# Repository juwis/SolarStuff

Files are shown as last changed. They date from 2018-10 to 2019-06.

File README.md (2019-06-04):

# SolarStuff on SolarFlight.info
1. brushless esc with integrated MPPT
 * [Software](https://github.com/juwis/SolarStuff/tree/master/src/autompptbldc)
 * [Hardware](https://github.com/juwis/SolarStuff/tree/master/hardware)
2. Solar Flight optimized Propellers
 * [CAD Data, Prop Data](https://github.com/juwis/SolarStuff/tree/master/props)
3. ...

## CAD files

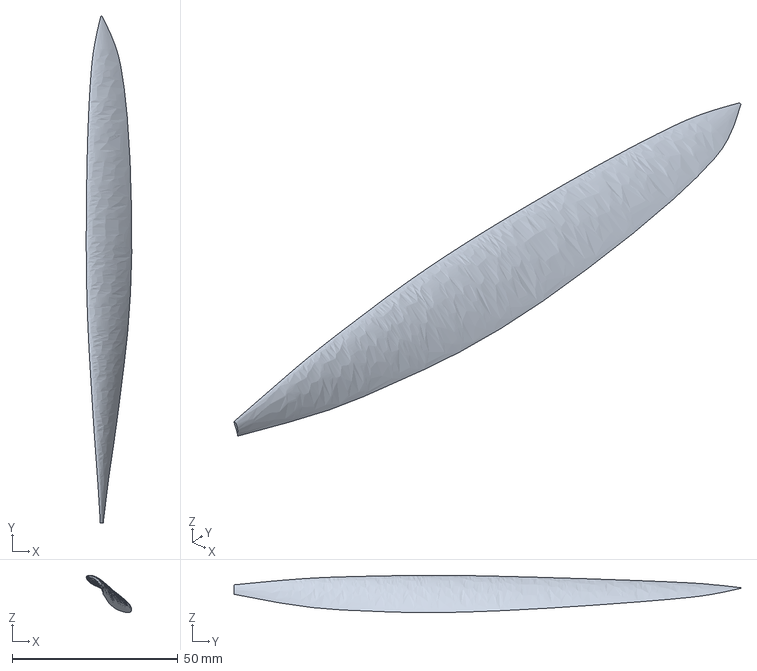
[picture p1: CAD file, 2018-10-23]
props/PROP_NG/13x18_schmal.igs
13.7 x 153.0 x 11.3 mm

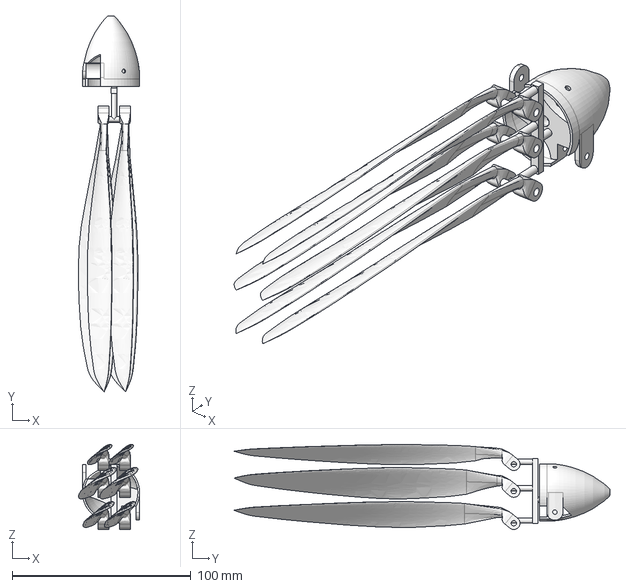
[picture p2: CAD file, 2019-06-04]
props/triple_size_spinner_4mm.stp
34.3 x 210.3 x 47.5 mm

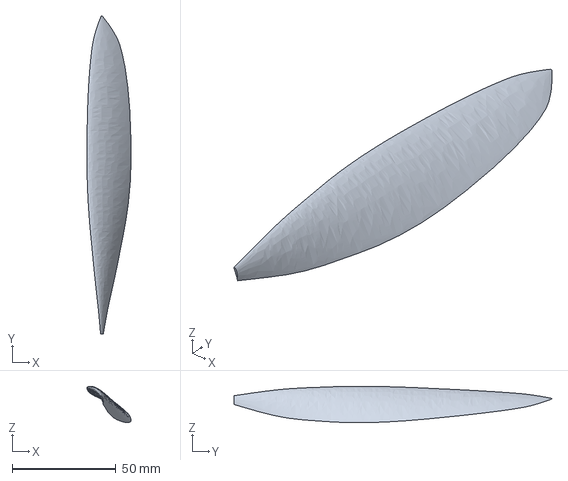
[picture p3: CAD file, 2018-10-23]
props/PROP_NG/13x18_breit.igs
21.2 x 153.0 x 17.5 mm

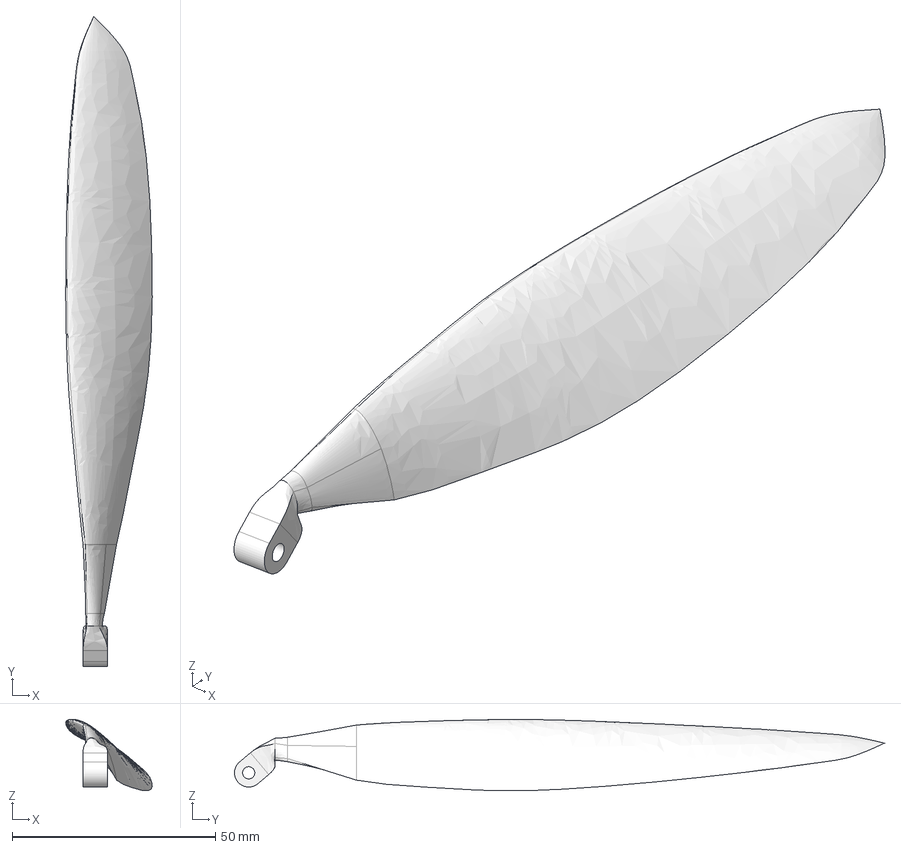
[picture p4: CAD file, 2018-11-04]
props/13x18_breit_blatthalter.stp
21.3 x 160.0 x 17.6 mm

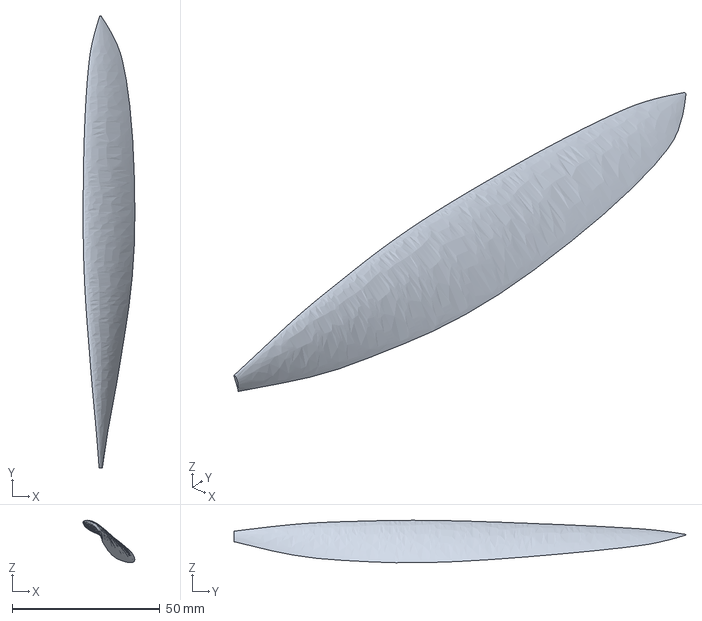
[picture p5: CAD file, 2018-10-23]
props/PROP_NG/13x18_mittel.igs
17.5 x 153.0 x 14.4 mm

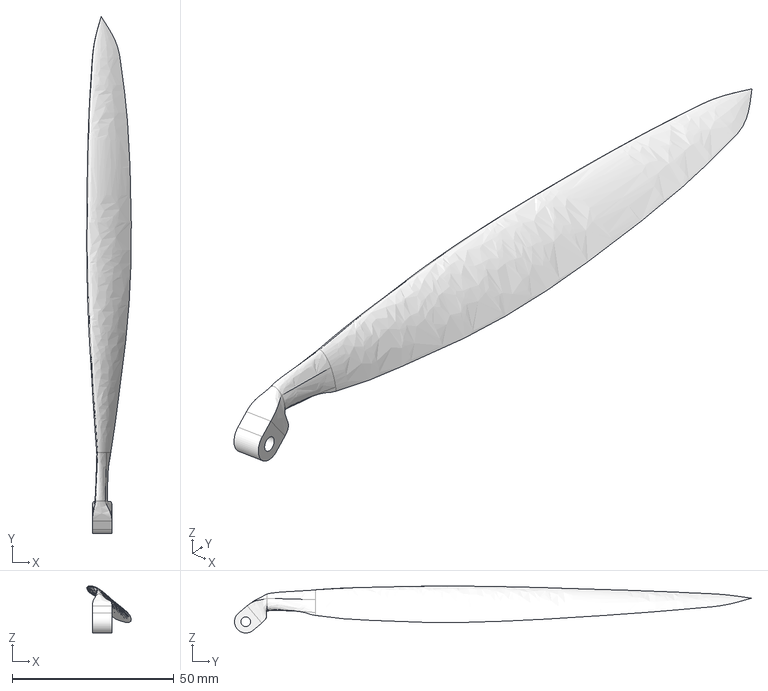
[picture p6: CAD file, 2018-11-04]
props/13x18_schmal_blatthalter.stp
13.8 x 160.0 x 14.5 mm

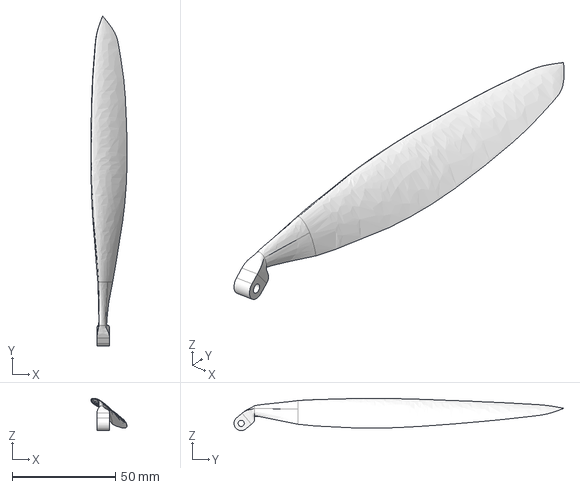
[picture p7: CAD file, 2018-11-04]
props/13x18_mittell_blatthalter.stp
17.6 x 160.0 x 15.6 mm

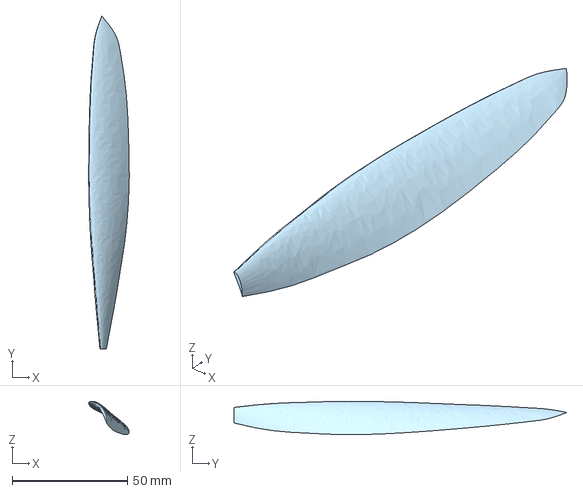
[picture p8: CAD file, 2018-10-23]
props/13x18_mittel_solid.step
17.6 x 144.5 x 14.4 mm

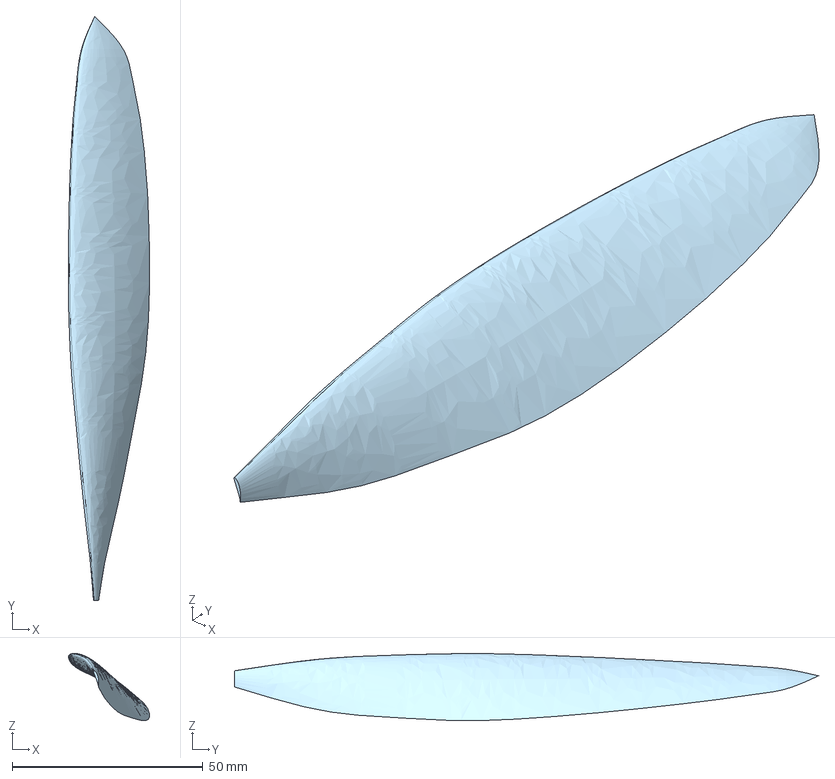
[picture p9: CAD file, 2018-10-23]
props/13x18_breit_solid.step
21.3 x 153.0 x 17.6 mm

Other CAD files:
props/triple_size_spinner_3.17mm.stp
props/13x18_schmal_solid.step

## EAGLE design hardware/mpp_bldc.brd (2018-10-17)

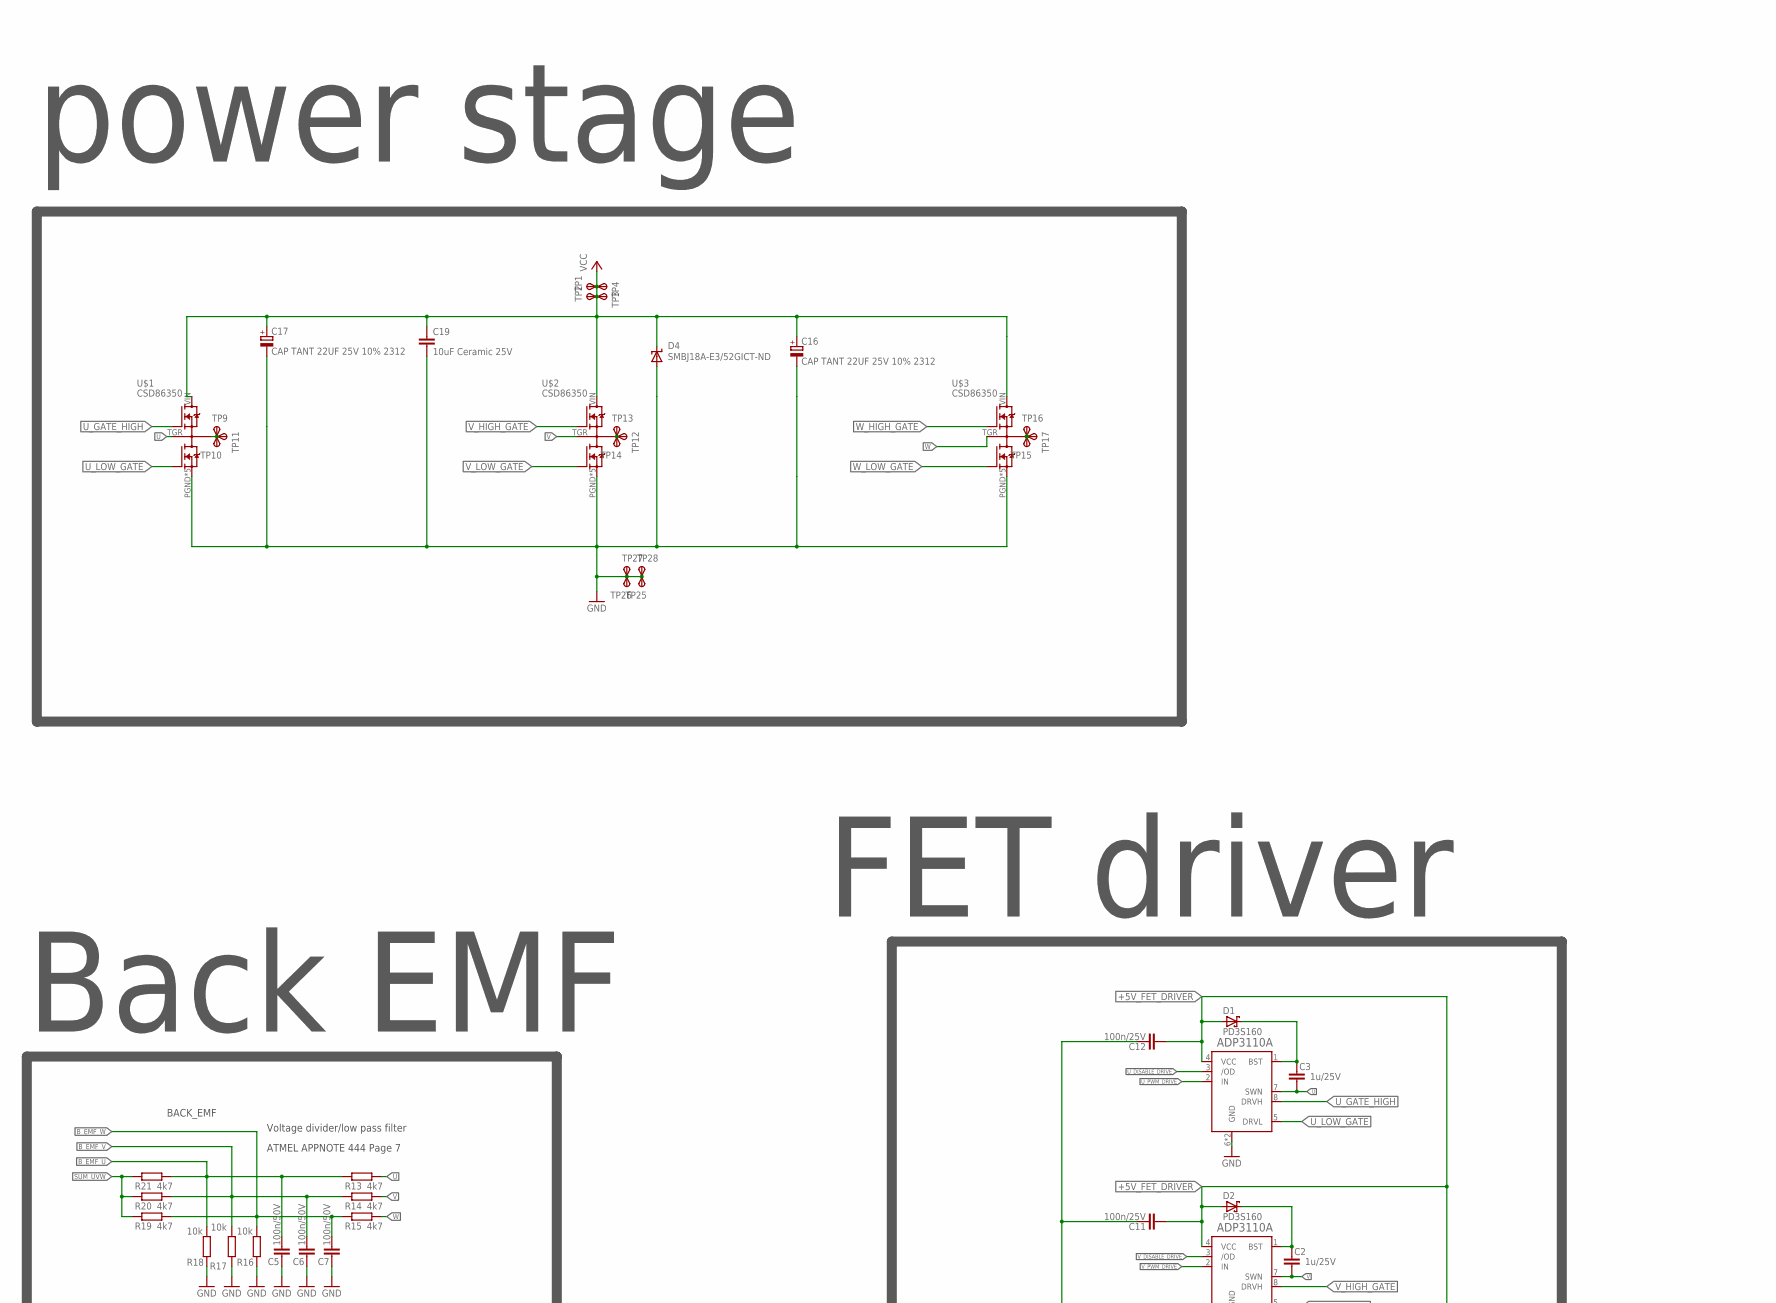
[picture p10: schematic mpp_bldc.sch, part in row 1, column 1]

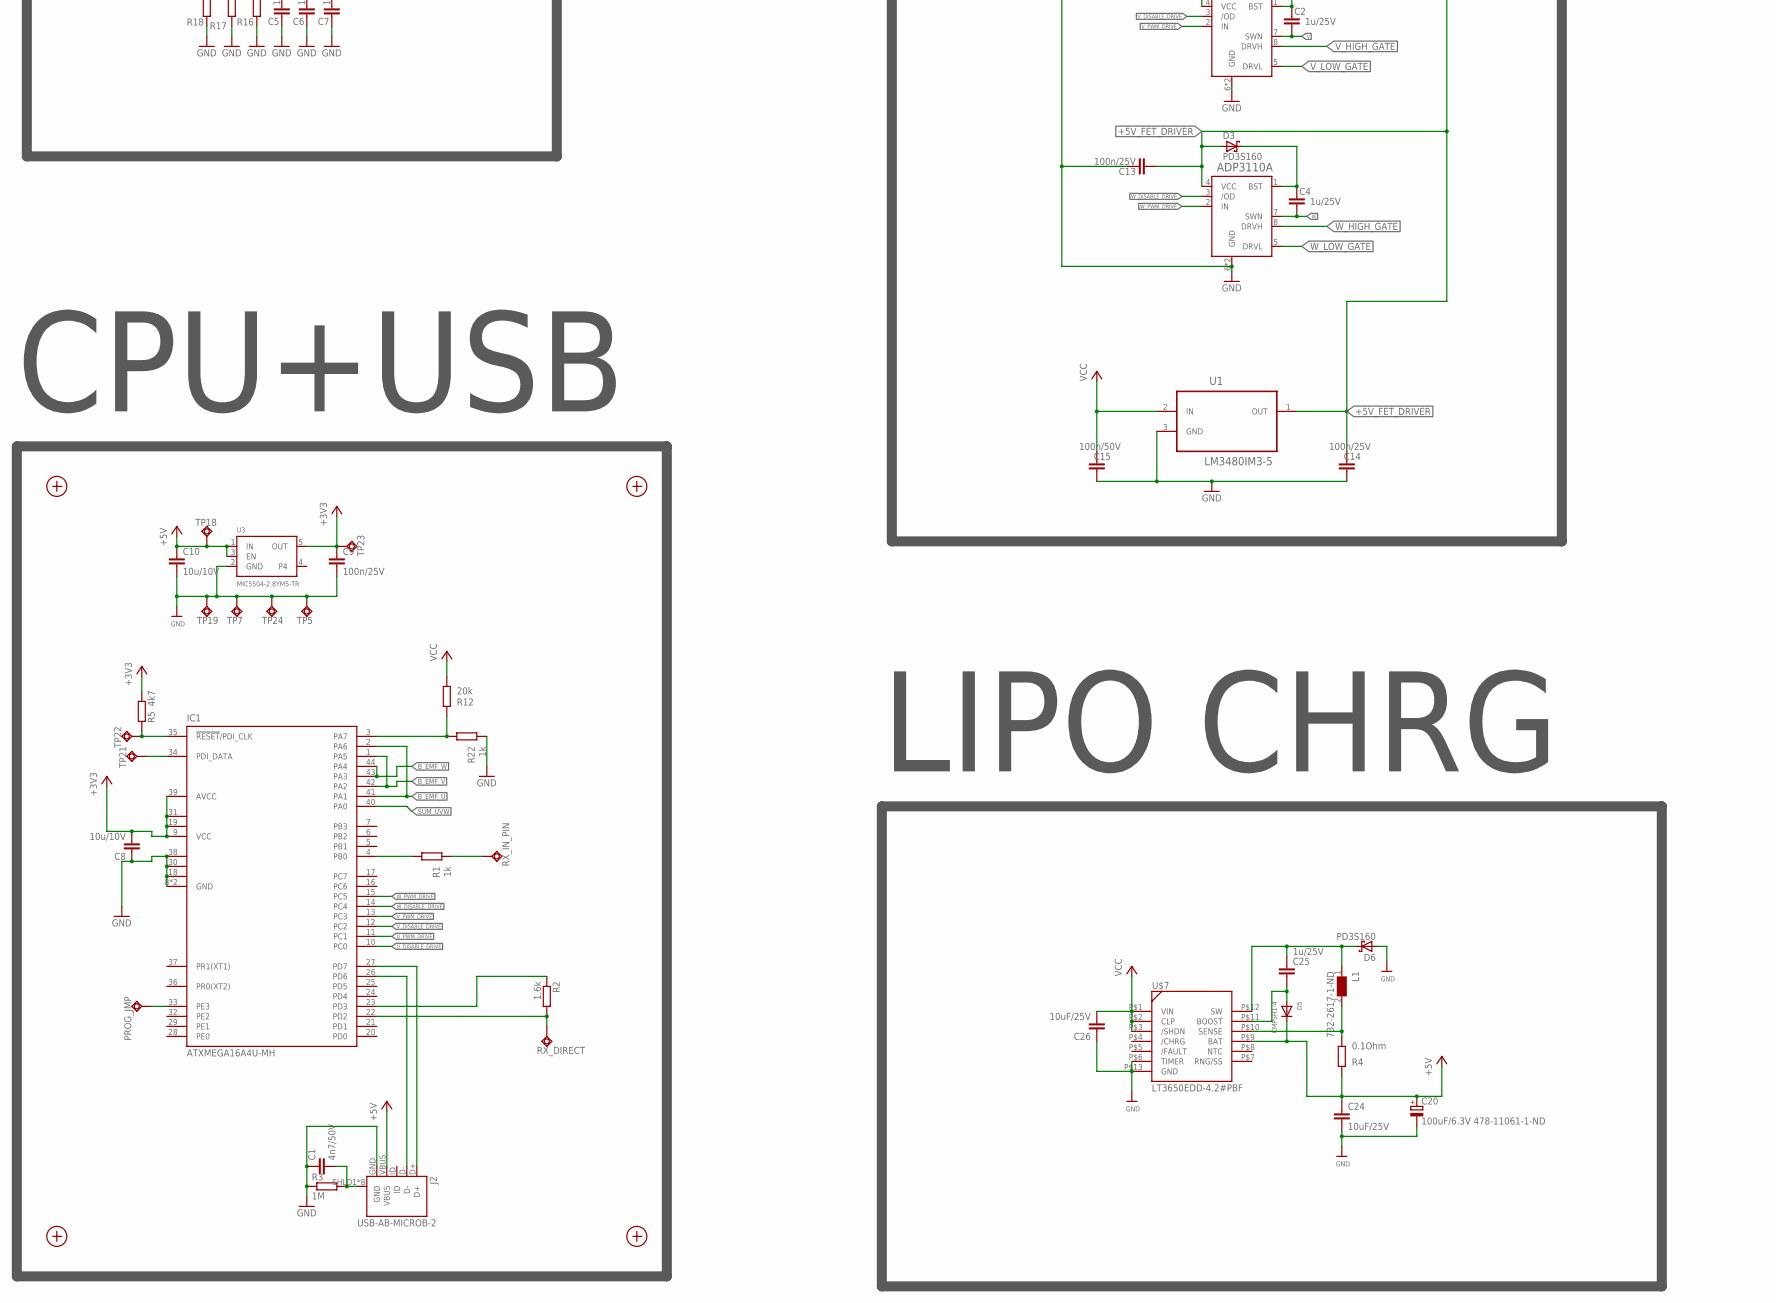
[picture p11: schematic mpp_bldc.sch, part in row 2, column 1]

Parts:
C1: 4n7/50V; C0603
C2, C3, C4, C25: 1u/25V; C0603
C5, C6, C7, C15: 100n/50V; C0603
C8, C10: 10u/10V; C0603K
C9, C11, C12, C13, C14: 100n/25V; C0603
C16, C17: CAP TANT 22UF 25V 10% 2312; C/6032-28R
C19: 10uF Ceramic 25V; C1206
C20: 100uF/6.3V 478-11061-1-ND; CT7343
C24, C26: 10uF/25V; C0805
D1, D2, D3, D6: PD3S160; POWERDI323
D4: SMBJ18A-E3/52GICT-ND; SMBJ
D5: CMPSH1-4; SOT23-R
IC1: ATXMEGA16A4U-MH; MLF44-TH
J2: USB-AB-MICROB-2; USB-MICROB-10118194
L1: 732-2617-1-ND; WE-TPC_2828
PROG_JMP: TPSQTP19SQ; TP19SQ
R1, R22: 1k; R0603
R2: 1.6k; R0603
R3: 1M; R0603
R4: 0.1Ohm; R0402
R5, R13, R14, R15, R19, R20, R21: 4k7; R0603
R12: 20k; R0603
R16, R17, R18: 10k; R0603
RX_DIRECT: TPSQTP19SQ; TP19SQ
RX_IN_PIN: TPSQTP19SQ; TP19SQ
TP1, TP2, TP3, TP4, TP9, TP10, TP11, TP12, TP13, TP14, TP15, TP16, TP17, TP25, TP26, TP27, TP28: TPSTP20SQ; TP20SQ
TP5, TP7, TP18, TP19: TPSQTP19SQ; TP19SQ
TP21: TPSQTP15R; TP15R
TP22, TP23, TP24: TPSQTP14SQ; TP14SQ
U1: LM3480IM3-5; SOT95P251X112-3N
U3: MIC5504-2.8YM5-TR; SOT23-5
U$1, U$2, U$3: CSD86350; Q5D
U$4, U$5, U$6: ADP3110A; DFN-8
U$7: LT3650EDD-4.2#PBF; 12-WFDFN
X1, X2, X3, X4: PASSER-07; PASSER_07MM

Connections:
+3V3: C8.2, C9.1, IC1.9 (VCC), IC1.19 (VCC1), IC1.31 (VCC2), IC1.39 (AVCC), R5.1, TP23.TP, U3.5 (OUT)
+5V: C10.1, C20.+, C24.1, D5.3 (C), J2.VBUS, R4.2, TP18.TP, U3.1 (IN), U3.3 (EN), U$7.P$9 (BAT)
+5V_FET_DRIVER: C11.2, C12.2, C13.2, C14.2, D1.A, D2.A, D3.A, U1.1 (OUT), U$4.4 (VCC), U$5.4 (VCC), U$6.4 (VCC)
B_EMF_U: C5.1, IC1.2 (PA6), IC1.41 (PA1), R13.2, R18.1, R21.1
B_EMF_V: C6.1, IC1.1 (PA5), IC1.42 (PA2), R14.2, R17.1, R20.1
B_EMF_W: C7.1, IC1.43 (PA3), IC1.44 (PA4), R15.2, R16.1, R19.1
GND: C1.1, C5.2, C6.2, C7.2, C8.1, C9.2, C10.2, C11.1, C12.1, C13.1, C14.1, C15.1, C16.-, C17.-, C19.2, C20.-, C24.2, C26.1, D4.A, D6.A, IC1.8 (GND), IC1.18 (GND1), IC1.30 (GND2), IC1.38 (GND3), IC1.TH (GND), J2.GND, R3.1, R16.2, R17.2, R18.2, R22.1, TP5.TP, TP7.TP, TP19.TP, TP24.TP, TP25.TP, TP26.TP, TP27.TP, TP28.TP, U1.3 (GND), U3.2 (GND), U$1.PGND, U$1.PGND0 (PGND), U$1.PGND1 (PGND), U$1.PGND2 (PGND), U$1.PGND3 (PGND), U$2.PGND, U$2.PGND0 (PGND), U$2.PGND1 (PGND), U$2.PGND2 (PGND), U$2.PGND3 (PGND), U$3.PGND, U$3.PGND0 (PGND), U$3.PGND1 (PGND), U$3.PGND2 (PGND), U$3.PGND3 (PGND), U$4.6 (GND), U$4.PAD (GND), U$5.6 (GND), U$5.PAD (GND), U$6.6 (GND), U$6.PAD (GND), U$7.P$6 (TIMER), U$7.P$13 (GND)
unnamed: IC1.33 (PE3), PROG_JMP.TP
unnamed: IC1.3 (PA7), R12.2, R22.2
unnamed: C3.2, D1.C, U$4.1 (BST)
unnamed: IC1.27 (PD7), J2.D+
unnamed: IC1.26 (PD6), J2.D-
unnamed: C2.2, D2.C, U$5.1 (BST)
unnamed: C4.2, D3.C, U$6.1 (BST)
unnamed: C25.1, D6.C, L1.1, U$7.P$12 (SW)
unnamed: L1.2, R4.1, U$7.P$10 (SENSE)
unnamed: C1.2, J2.SHLD1 (SHIELD), J2.SHLD2 (SHIELD), J2.SHLD3 (SHIELD), J2.SHLD4 (SHIELD), J2.SHLD5 (SHIELD), J2.SHLD6 (SHIELD), J2.SHLD7 (SHIELD), J2.SHLD8 (SHIELD), R3.2
unnamed: C25.2, D5.1 (A), U$7.P$11 (BOOST)
PDI_DATA: IC1.34 (PDI_DATA), TP21.TP
RC_SIG_IC: IC1.4 (PB0), R1.2
RC_SIG_RCV: R1.1, RX_IN_PIN.TP
RST_PDICLK: IC1.35 (!RESET!/PDI_CLK), R5.2, TP22.TP
RX_DIRECT_PD2: IC1.22 (PD2), R2.2, RX_DIRECT.TP
SUM_UVW: IC1.40 (PA0), R19.2, R20.2, R21.2
TX_DIRECT_PD3: IC1.23 (PD3), R2.1
U: C3.1, R13.1, U$1.TGR, U$4.7 (SWN)
UMOT: TP9.TP, TP10.TP, TP11.TP, U$1.VSW0 (VSW), U$1.VSW1 (VSW), U$1.VSW2 (VSW)
U_DISABLE_DRIVE: IC1.10 (PC0), U$4.3 (/OD)
U_GATE_HIGH: U$1.TG, U$4.8 (DRVH)
U_LOW_GATE: U$1.BG, U$4.5 (DRVL)
U_PWM_DRIVE: IC1.11 (PC1), U$4.2 (IN)
V: C2.1, R14.1, U$2.TGR, U$5.7 (SWN)
VCC: C15.2, C16.+, C17.+, C19.1, C26.2, D4.C, R12.1, TP1.TP, TP2.TP, TP3.TP, TP4.TP, U1.2 (IN), U$1.VIN, U$2.VIN, U$3.VIN, U$7.P$1 (VIN), U$7.P$2 (CLP), U$7.P$3 (/SHDN)
VMOT: TP12.TP, TP13.TP, TP14.TP, U$2.VSW0 (VSW), U$2.VSW1 (VSW), U$2.VSW2 (VSW)
V_DISABLE_DRIVE: IC1.12 (PC2), U$5.3 (/OD)
V_HIGH_GATE: U$2.TG, U$5.8 (DRVH)
V_LOW_GATE: U$2.BG, U$5.5 (DRVL)
V_PWM_DRIVE: IC1.13 (PC3), U$5.2 (IN)
W: C4.1, R15.1, U$3.TGR, U$6.7 (SWN)
WMOT: TP15.TP, TP16.TP, TP17.TP, U$3.VSW0 (VSW), U$3.VSW1 (VSW), U$3.VSW2 (VSW)
W_DISABLE_DRIVE: IC1.14 (PC4), U$6.3 (/OD)
W_HIGH_GATE: U$3.TG, U$6.8 (DRVH)
W_LOW_GATE: U$3.BG, U$6.5 (DRVL)
W_PWM_DRIVE: IC1.15 (PC5), U$6.2 (IN)

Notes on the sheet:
Voltage divider/low pass filter
ATMEL APPNOTE 444 Page 7
BACK_EMF
power stage
FET driver
LIPO CHRG
Back EMF
CPU+USB

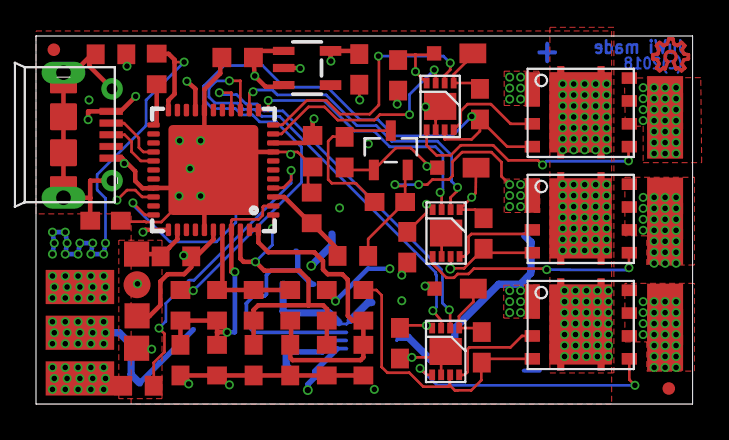
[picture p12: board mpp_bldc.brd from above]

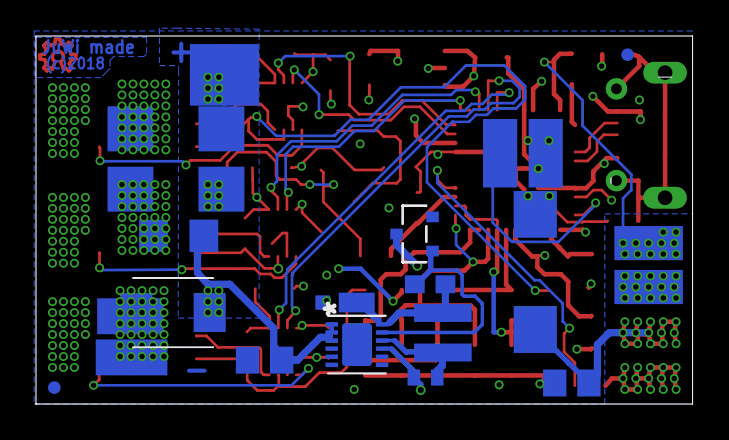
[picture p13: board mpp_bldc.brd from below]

Board: 4 copper layers, 36.5 x 20.4 mm, 89 parts (27 on the bottom side), 44 nets.

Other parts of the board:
U$11: OSHW_2MM

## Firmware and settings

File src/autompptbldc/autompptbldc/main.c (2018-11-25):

/*
* autompptbldc.c
*
* Created: 8/3/2018 12:49:07 PM
* Author : juwi
*/

#include "includes.h"
#include "constants.h"
#include "setup.h"
#include "uart.h"

//#define DEBUG_SERIAL


volatile unsigned char COMMUTATION_INDEX_SENSED, COMMUTATION_INDEX;
volatile uint32_t RT_TIME[6];
volatile uint16_t ADC;
volatile unsigned int BREAK;
volatile uint16_t average_time;

volatile float COMMUTATION_TIMING_FACTOR;

volatile uint8_t MOTOR_TO_SLOW;

#define HYSMODE	AC_HYSMODE_SMALL_gc

// comparator functions
static inline void SET_COMP_RSG(){
	ACA.AC0CTRL=AC_INTMODE_RISING_gc | AC_INTLVL_HI_gc | (1<<AC_HSMODE_bp) | HYSMODE | (1<<AC_ENABLE_bp);
}

static inline void  SET_COMP_FNG(){
	ACA.AC0CTRL=AC_INTMODE_FALLING_gc | AC_INTLVL_HI_gc | (1<<AC_HSMODE_bp) | HYSMODE | (1<<AC_ENABLE_bp);
}

static inline void  SET_COMP_BTH(){
	ACA.AC0CTRL=AC_INTMODE_BOTHEDGES_gc | AC_INTLVL_HI_gc | (1<<AC_HSMODE_bp) | HYSMODE | (1<<AC_ENABLE_bp);
}

static inline void  SET_COMP_OFF(){
	ACA.AC0CTRL=AC_INTMODE_RISING_gc | AC_INTLVL_OFF_gc | (1<<AC_HSMODE_bp) | HYSMODE | (1<<AC_ENABLE_bp);
}



void set_ac_interrupt(){
	switch (COMMUTATION_INDEX_SENSED){
		case 0:
		ACA.AC0MUXCTRL = SENSE_0_FNG_AC_MUXPOS | AC_MUXNEG_PIN0_gc;
		SET_COMP_FNG();
		break;
		case 1:
		ACA.AC0MUXCTRL = SENSE_1_RSG_AC_MUXPOS | AC_MUXNEG_PIN0_gc;
		SET_COMP_RSG();
		break;
		case 2:
		ACA.AC0MUXCTRL = SENSE_2_FNG_AC_MUXPOS | AC_MUXNEG_PIN0_gc;
		SET_COMP_FNG();
		break;
		case 3:
		ACA.AC0MUXCTRL = SENSE_3_RSG_AC_MUXPOS | AC_MUXNEG_PIN0_gc;
		SET_COMP_RSG();
		break;
		case 4:
		ACA.AC0MUXCTRL = SENSE_4_FNG_AC_MUXPOS | AC_MUXNEG_PIN0_gc;
		SET_COMP_FNG();
		break;
		case 5:
		ACA.AC0MUXCTRL = SENSE_5_RSG_AC_MUXPOS | AC_MUXNEG_PIN0_gc;
		SET_COMP_RSG();
		break;
	}
}


uint16_t adc_read(void)
{
	ADC_CH_t *adc_channel=&ADCA.CH0;
	unsigned int value;

	// Wait for the AD conversion to complete
	while ((adc_channel->INTFLAGS & ADC_CH_CHIF_bm)==0);

	adc_channel->INTFLAGS=ADC_CH_CHIF_bm;
	
	((unsigned char *) &value)[0]=adc_channel->RESL;
	((unsigned char *) &value)[1]=adc_channel->RESH;
	uint16_t res = (((((float)value * 21.0) / 4096.0)) * 1000) - 900;
	return res;
}



#define ELEM_SWAP(a,b) { register uint16_t t=(a);(a)=(b);(b)=t; }

uint16_t quick_select(volatile uint16_t arr[], uint8_t n)
{
	uint16_t low, high ;
	uint16_t median;
	uint16_t middle, ll, hh;

	low = 0 ; high = n-1 ; median = (low + high) / 2;
	for (;;) {
		if (high <= low) /* One element only */
		return arr[median] ;

		if (high == low + 1) {  /* Two elements only */
			if (arr[low] > arr[high])
			ELEM_SWAP(arr[low], arr[high]) ;
			return arr[median] ;
		}

		/* Find median of low, middle and high items; swap into position low */
		middle = (low + high) / 2;
		if (arr[middle] > arr[high])    ELEM_SWAP(arr[middle], arr[high]) ;
		if (arr[low] > arr[high])       ELEM_SWAP(arr[low], arr[high]) ;
		if (arr[middle] > arr[low])     ELEM_SWAP(arr[middle], arr[low]) ;

		/* Swap low item (now in position middle) into position (low+1) */
		ELEM_SWAP(arr[middle], arr[low+1]) ;

		/* Nibble from each end towards middle, swapping items when stuck */
		ll = low + 1;
		hh = high;
		for (;;) {
			do ll++; while (arr[low] > arr[ll]) ;
			do hh--; while (arr[hh]  > arr[low]) ;

			if (hh < ll)
			break;

			ELEM_SWAP(arr[ll], arr[hh]) ;
		}

		/* Swap middle item (in position low) back into correct position */
		ELEM_SWAP(arr[low], arr[hh]) ;

		/* Re-set active partition */
		if (hh <= median)
		low = ll;
		if (hh >= median)
		high = hh - 1;
	}
}

#undef ELEM_SWAP

// Analog Comparator 0 for PORTA interrupt service routine
ISR(ACA_AC0_vect)
{
	static uint16_t commutation_time = 0;
	static uint16_t comperator_sleep_time = 0;

	uint16_t last_rt_time = (RT_TIME[0] + RT_TIME[1] + RT_TIME[2] + RT_TIME[3] + RT_TIME[4] + RT_TIME[5]) / 6;
		
	RT_TIME[COMMUTATION_INDEX_SENSED] = TCD0.CNT;

	// tcd0 measures the commutation time, reset to zero
	// tcd0 is also used to delay the commutation (aka timing) and to wait for the next phase change comparator window
	TCD0.CNT = 0;
	TCD0.INTCTRLA=TC_ERRINTLVL_OFF_gc | TC_OVFINTLVL_MED_gc;


	#ifdef DEBUG_SERIAL
	uart_putchar('0', NULL);
	uart_putchar('\r', NULL);
	uart_putchar('\n', NULL);
	#endif

	//Disable Comparator Interrupt - gets re enabled in Commutation Timer
	SET_COMP_OFF();

	//now we look, in startup we don't do any timing or waiting, all is fired up immediately
	if(MOTOR_TO_SLOW == 1){
		//both are not usable, so immediate fire by setting to 1 and resetting the timer
		commutation_time = 1;
		comperator_sleep_time = 1;

		//RT_TIME[COMMUTATION_INDEX_SENSED] = 65535; //max value
		MOTOR_TO_SLOW = 0; //reset here, perhaps we are now fast enough...
		
	}else{
		
		average_time = last_rt_time;
		
		commutation_time = average_time / 24;
		comperator_sleep_time = average_time / 32; // time ignore comparator changes


	}

	//printf("CT: %u | CST: %u\r\n", commutation_time, comperator_sleep_time);

	TCD0.CCA = comperator_sleep_time;
	TCD0.CCB = commutation_time;
	TCD0.INTCTRLB=TC_CCBINTLVL_HI_gc| TC_CCAINTLVL_HI_gc; // waiting timer is urgent...

	//increase COMMUTATION_INDEX_SENSED by one looping in the range 0-5 via the fabulous modulo operator %
	COMMUTATION_INDEX_SENSED = (COMMUTATION_INDEX_SENSED + 1) % 6;
}

// Timer/Counter TCD1 Overflow/Underflow interrupt service routine
//RPM Speed Counter, if it overflows the Motor is Spinning slower than 128ms per phase change
ISR(TCD0_OVF_vect)
{
	#ifdef DEBUG_SERIAL
	uart_putchar('s', NULL);
	uart_putchar('\r', NULL);
	uart_putchar('\n', NULL);
	#endif

	TCD0.INTCTRLA=TC_ERRINTLVL_OFF_gc | TC_OVFINTLVL_OFF_gc;
	MOTOR_TO_SLOW=1;
}


// Timer/Counter TCD0 Compare/Capture A interrupt service routine
// re enable the analog comparator for the next phase
ISR(TCD0_CCA_vect)
{
	#ifdef DEBUG_SERIAL
	uart_putchar('1', NULL);
	uart_putchar('\r', NULL);
	uart_putchar('\n', NULL);
	#endif

	if (TCD0.INTFLAGS & TC0_CCAIF_bm){
		TCD0.INTFLAGS|=TC0_CCAIF_bm;
	}
	// re enable the expected new analog comparator match
	set_ac_interrupt();
	//TCD0.INTCTRLB=TC_CCBINTLVL_HI_gc | TC_CCAINTLVL_HI_gc;
}

// Timer/Counter TCD0 Compare/Capture B interrupt service routine
// Timing delay routine
ISR(TCD0_CCB_vect)
{
	#ifdef DEBUG_SERIAL
	uart_putchar('2', NULL);
	uart_putchar('\r', NULL);
	uart_putchar('\n', NULL);
	#endif

	if (TCD0.INTFLAGS & TC0_CCBIF_bm){ TCD0.INTFLAGS|=TC0_CCBIF_bm;
	}
	// this is the timing delay timer, used to wait an arbitrary amount and delay the commutation till then
	// in here the index is updated and the timer is set to wait for the next window in which the analog
	// comparator can wait for the phase change
	
	//TCD0.INTCTRLB = TC_CCBINTLVL_HI_gc | TC_CCAINTLVL_HI_gc;
	
	COMMUTATION_INDEX = COMMUTATION_INDEX_SENSED;
	
	SET_PHASE_PWM(COMMUTATION_INDEX, BREAK);
}

static inline void my_delay_ms(int ms)
{
	while (0 < ms)
	{
		_delay_ms(1);
		--ms;
	}
}

void startup(uint16_t startup_pwm, uint8_t hard_commutations,uint8_t wait_first, int16_t phase_delay_start, uint8_t phase_delay_decrement){

	asm("cli");
	//Disable Comparator Interrupt - re enabled in Commutation Timer
	SET_COMP_OFF();

	BREAK = 0;
	
	SET_PHASE_PWM(COMMUTATION_INDEX_SENSED, BREAK);
	COMMUTATION_INDEX = COMMUTATION_INDEX_SENSED;
	
	TCC0.CCA = startup_pwm;
	my_delay_ms(wait_first);
	
	for(uint8_t i=0; i<hard_commutations; i++){
		COMMUTATION_INDEX_SENSED = (COMMUTATION_INDEX_SENSED + 1) % 6;
		COMMUTATION_INDEX = COMMUTATION_INDEX_SENSED;
		SET_PHASE_PWM(COMMUTATION_INDEX_SENSED, BREAK);
		my_delay_ms(phase_delay_start);

		//prevent phase_delay to get below zero (wrap around)

		phase_delay_start -= phase_delay_decrement;
		phase_delay_start = phase_delay_start  > 3 ? phase_delay_start : 3;
	}
	COMMUTATION_INDEX = COMMUTATION_INDEX_SENSED;
	set_ac_interrupt();
	asm("sei");
}

void beep(uint16_t beep_pwm, uint16_t length, uint8_t tone){
	asm("cli");
	TCC0.CCA = beep_pwm;

	for(uint16_t i=0; i<length; i++){
		SET_PHASE_PWM(0, 0);
		for(uint8_t delay=0; delay < tone; delay++){
			_delay_us(100);
		}
		SET_PHASE_PWM(1, 0);
		for(uint8_t delay=0; delay < tone; delay++){
			_delay_us(100);
		}
	}

	SET_PHASE_PWM(COMMUTATION_INDEX, BREAK);
	asm("sei");

}

void beep_short_low()
{
	beep(0x04f, 250, 3);
}

void beep_short_high()
{
	beep(0x04f, 400, 2);
}

void beep_long_low()
{
	beep(0x04f, 800, 3);
}

void beep_long_high()
{
	beep(0x04f, 1200, 2);
}

uint16_t get_transmitter_power(){
	static uint16_t power = 1000;
	volatile uint16_t servopulse = 0;
	uint16_t normalized_power = 0;
	servopulse = TCE0_CCABUF;


	if(servopulse > TRANSMITTER_MIN_PULSE && servopulse < TRANSMITTER_MAX_PULSE){
		//seems to be in a reasonable window
		//infinite response filtering + normalizing (0-1000) applied in the next line
		float norm_divisor = ((float)((float)TRANSMITTER_MAX_PULSE - (float)TRANSMITTER_MIN_PULSE)/1000.0);
		
		power += (((servopulse - TRANSMITTER_MIN_PULSE) / norm_divisor) - power) / TRANSMITTER_FILTER_STRENGTH; //the division normalizes the value to 0-1000, the 
	}else{
		//wrong signal received, reset to zero (which is 1000 here)
		power = 1000;
	}
	
	normalized_power = 1000 - power; //invert because it is getting lower the more the trigger is pushed...
	
	//now add full and no throttle positions, mix them in
	if (normalized_power < NORMALIZED_MIN_THROTTLE){
		return 0;
	}

	if (normalized_power > NORMALIZED_MIN_THROTTLE && normalized_power < NORMALIZED_MAX_THROTTLE){
		return (normalized_power - NORMALIZED_MIN_THROTTLE) + (((NORMALIZED_MIN_THROTTLE * normalized_power) / NORMALIZED_MAX_THROTTLE) * 2);
	}

	if (normalized_power > NORMALIZED_MAX_THROTTLE){
		return 1000;
	}

	return normalized_power;
}



int main(void)
{
	
	//****************************************************************************************************
	// local variables

	uint32_t transmitter_power = 0;
	uint16_t out_power = 0;
	//****************************************************************************************************
	// globals init
	BREAK = 1;
	average_time = 0;
	
	// from the Analog comparator interrupt this is set:
	COMMUTATION_INDEX_SENSED = 0;
	// from the timing interrupt this is set(and then immediately used by pwm):
	COMMUTATION_INDEX = 0;
	
	// Round trip time counter, overflow (65535) @ ca 128ms per Phase(60deg)
	RT_TIME[0] = 0;
	RT_TIME[1] = 0;
	RT_TIME[2] = 0;
	RT_TIME[3] = 0;
	RT_TIME[4] = 0;
	RT_TIME[5] = 0;
	
	//ADC Value
	ADC = 0;
	
	// set if rpm counter overflows
	MOTOR_TO_SLOW = 0;
	
	//TIMING Setting
	COMMUTATION_TIMING_FACTOR = 0.2;
	
	uc_setup();
	uart_setup();
	
	
	// "and that's where the fun starts" (Patrick Jane)

	asm("sei");

	TCC0.CCA = 0x00; //no power applied
	BREAK = 1; //break applied
	beep_short_low();
	
	_delay_ms(100);
	beep_short_high();
		
	// wait for no power from transmitter, a hundred times with no exception
	uint8_t no_power_count = 100;
	while(1){


		if(get_transmitter_power() == 0){
			no_power_count--;
			_delay_ms(5);
		}else{
			no_power_count = 100;
		}
		
		//break if we got no power from tx
		if(no_power_count < 1){
			beep_short_low();
			_delay_ms(100);
			beep_long_high();
			
			break;
		}
	}
	
	
	
	while (1)
	{
		ADC=adc_read();

		transmitter_power = get_transmitter_power();
		
		//adc_filtered += (((double)ADC - (double)adc_filtered) / 32.0);
		
		//printf("%u mV\r\n", adc_filtered);	
		
		_delay_us(100);
	
		if(BREAK == 1){
			if(transmitter_power > 0){
				startup(0x01f, 3, 150, 50, 5);
			}
		}
		
		if(transmitter_power == 0){
			TCC0.CCA = 0x00; //shut down power
			BREAK = 1;
			continue;
		}
		
		//this makes sense, because we are getting here after startup from the previous if...
		//an else clause would mean that the power setting would be delayed for cycle time + a bit...
		if(BREAK == 0){
			//we are probably running
			uint16_t out_power_transmitter = (transmitter_power * PWM_TOP_PER) / 1000;
			
			out_power_transmitter = out_power_transmitter > PWM_TOP_PER ? PWM_TOP_PER : out_power_transmitter; //limit to PWM_TOP Value
			
			if(out_power < out_power_transmitter && ADC > MPPT_VOLTAGE){
				out_power++;
			}
			
			if(out_power > out_power_transmitter){
				out_power = out_power_transmitter;
			}
			
			if(out_power > 0 && ADC < MPPT_VOLTAGE){
				out_power--;
			}
			
			TCC0.CCA = out_power;
		}
		
		
	}
}

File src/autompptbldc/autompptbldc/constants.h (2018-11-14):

#ifndef CONSTANTS_H
#define CONSTANTS_H

#define MPPT_VOLTAGE	8466

#define TRANSMITTER_MIN_PULSE	17000
#define TRANSMITTER_MAX_PULSE	31000
#define TRANSMITTER_FILTER_STRENGTH	8

#define NORMALIZED_MIN_THROTTLE	50
#define NORMALIZED_MAX_THROTTLE	(1000 - NORMALIZED_MIN_THROTTLE)


#define PHASE_U_HIGH     0b00000011
#define PHASE_U_LOW      0b00000001
#define PHASE_U_PWM_PIN  0b00000010
#define PHASE_U_FLOAT    0b00000000
#define PHASE_V_HIGH     0b00001100
#define PHASE_V_LOW      0b00000100
#define PHASE_V_PWM_PIN  0b00001000
#define PHASE_V_FLOAT    0b00000000
#define PHASE_W_HIGH     0b00110000
#define PHASE_W_LOW      0b00010000
#define PHASE_W_PWM_PIN  0b00100000
#define PHASE_W_FLOAT    0b00000000

#define PHASE_0_ON                (PHASE_U_HIGH | PHASE_V_LOW | PHASE_W_FLOAT)
#define PHASE_1_ON                (PHASE_U_HIGH | PHASE_V_FLOAT | PHASE_W_LOW)
#define PHASE_2_ON                (PHASE_U_FLOAT | PHASE_V_HIGH | PHASE_W_LOW)
#define PHASE_3_ON                (PHASE_U_LOW | PHASE_V_HIGH | PHASE_W_FLOAT)
#define PHASE_4_ON                (PHASE_U_LOW | PHASE_V_FLOAT | PHASE_W_HIGH)
#define PHASE_5_ON                (PHASE_U_FLOAT | PHASE_V_LOW | PHASE_W_HIGH)

//make it indexable
uint8_t PHASE_ON[6] = {PHASE_0_ON, PHASE_1_ON, PHASE_2_ON, PHASE_3_ON, PHASE_4_ON, PHASE_5_ON};

#define PHASE_0_OFF				(PHASE_U_LOW | PHASE_V_LOW | PHASE_W_FLOAT)
#define PHASE_1_OFF				(PHASE_U_LOW | PHASE_V_FLOAT | PHASE_W_LOW)
#define PHASE_2_OFF				(PHASE_U_FLOAT | PHASE_V_LOW | PHASE_W_LOW)
#define PHASE_3_OFF				(PHASE_U_LOW | PHASE_V_LOW | PHASE_W_FLOAT)
#define PHASE_4_OFF				(PHASE_U_LOW | PHASE_V_FLOAT | PHASE_W_LOW)
#define PHASE_5_OFF				(PHASE_U_FLOAT | PHASE_V_LOW | PHASE_W_LOW)

//make it indexable
uint8_t PHASE_OFF[6] = {PHASE_0_OFF, PHASE_1_OFF, PHASE_2_OFF, PHASE_3_OFF, PHASE_4_OFF, PHASE_5_OFF};

#if 0
#define PHASE_0_PWM_PIN				(PHASE_U_PWM_PIN | PHASE_U_LOW)
#define PHASE_1_PWM_PIN				(PHASE_U_PWM_PIN | PHASE_U_LOW)
#define PHASE_2_PWM_PIN				(PHASE_V_PWM_PIN | PHASE_V_LOW)
#define PHASE_3_PWM_PIN				(PHASE_V_PWM_PIN | PHASE_V_LOW)
#define PHASE_4_PWM_PIN				(PHASE_W_PWM_PIN | PHASE_W_LOW)
#define PHASE_5_PWM_PIN				(PHASE_W_PWM_PIN | PHASE_W_LOW)
#else
#define PHASE_0_PWM_PIN			PHASE_U_PWM_PIN
#define PHASE_1_PWM_PIN			PHASE_U_PWM_PIN
#define PHASE_2_PWM_PIN			PHASE_V_PWM_PIN
#define PHASE_3_PWM_PIN			PHASE_V_PWM_PIN
#define PHASE_4_PWM_PIN			PHASE_W_PWM_PIN
#define PHASE_5_PWM_PIN			PHASE_W_PWM_PIN
#endif

//make it indexable
uint8_t PHASE_PWM_PIN[6] = {PHASE_0_PWM_PIN, PHASE_1_PWM_PIN, PHASE_2_PWM_PIN, PHASE_3_PWM_PIN, PHASE_4_PWM_PIN, PHASE_5_PWM_PIN};

#define PHASES_FLOAT			(PHASE_U_FLOAT | PHASE_V_FLOAT | PHASE_W_FLOAT)
#define PHASES_LOW_BREAK		(PHASE_U_LOW | PHASE_V_FLOAT | PHASE_W_LOW)
#define PHASES_HIGH_BREAK		(PHASE_U_HIGH | PHASE_V_HIGH | PHASE_W_HIGH)

#define SENSE_U_MUXPOS         AC_MUXPOS_PIN1_gc	//PortA Pin 1
#define SENSE_V_MUXPOS         AC_MUXPOS_PIN2_gc	//PortA Pin 2
#define SENSE_W_MUXPOS         AC_MUXPOS_PIN3_gc	//PortA Pin 3

// for PWM via the AWEX Unit we need to split the above information into three parts
// 
// - the actual PWMed pins
// - freewheeling enabled or not
// - Phase State
// and we will accomplish that by creating small inlined functions that set all up.

//the OUTput OVErride eNable register will take the pins that are switched
//PORTC is set to the static scheme for tha set phase.
static inline void  SET_PHASE_PWM(uint8_t phase, uint8_t breaking){
	if (breaking != 0){
		AWEXC.OUTOVEN = 0;
		PORTC.OUT = PHASES_LOW_BREAK;
	}else{
		//phase = (phase-1) %6;
		AWEXC.OUTOVEN = PHASE_PWM_PIN[phase];
		PORTC.OUT = PHASE_OFF[phase];
	}
}

#define SENSE_0_FNG_AC_MUXPOS	SENSE_W_MUXPOS
#define SENSE_1_RSG_AC_MUXPOS	SENSE_V_MUXPOS
#define SENSE_2_FNG_AC_MUXPOS	SENSE_U_MUXPOS
#define SENSE_3_RSG_AC_MUXPOS	SENSE_W_MUXPOS
#define SENSE_4_FNG_AC_MUXPOS	SENSE_V_MUXPOS
#define SENSE_5_RSG_AC_MUXPOS	SENSE_U_MUXPOS


#define PWM_TOP_PER		0x02FF

#endif //CONSTANTS_H

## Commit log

2018-09-16 new version, untested Servo input, running @30degr. timing
2018-09-20 initial HW release
    [mpp_bldc.brd, mpp_bldc.sch]
2018-09-21 tidy up
    [mpp_bldc.brd, mpp_bldc.sch]
2018-09-23 added open hardware symbol :)
    [mpp_bldc.brd, mpp_bldc.sch]
2018-10-12 2.8V Supply for uC reduces power draw further Cleanup and some values (ceramics) reduced to buyable ones
    [mpp_bldc.brd, mpp_bldc.sch]
2018-10-12 bugfix release, bad coding style leads to bad code...
    [constants.h]
2018-10-17 to be checked
    [mpp_bldc.brd, mpp_bldc.sch]
2018-10-17 Checked and cleaned up Hardware, repositioned 4 caps
    [mpp_bldc.brd, mpp_bldc.sch]
2018-10-23 prop data for solar plane
    [13x18_breit.igs, 13x18_mittel.igs, 13x18_schmal.igs]
2018-11-04 stronger base, stiffer design
    [13x18_breit_blatthalter.stp, 13x18_mittell_blatthalter.stp, 13x18_schmal_blatthalter.stp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]
2019-06-04 fixed missing holes, cleanup
    [13x18_breit_blatthalter.stp, 13x18_breit_solid.step, 13x18_mittel_solid.step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]
